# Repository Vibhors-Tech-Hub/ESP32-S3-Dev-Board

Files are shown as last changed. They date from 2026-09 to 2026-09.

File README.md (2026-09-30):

# ESP32-S3 Development Board (4-Layer PCB)

A professional-grade, high-performance **ESP32-S3 Development Board**. This hardware implementation uses a 4-layer PCB stackup to optimize signal integrity, accommodate controlled-impedance differential USB paths, and provide a low-noise ground reference for the RF module's wireless performance.

## Features
* **Core Processor:** Powered by the **ESP32-S3-MINI-1** module featuring high-speed 2.4 GHz Wi-Fi and Bluetooth LE connectivity.
* **Dual USB Type-C Connectivity:** 
  * **USB OTG Port:** Direct native connection to the ESP32-S3 USB pins (IO19/IO20) for USB Host/Device applications.
  * **USB to UART Port:** Dedicated programming and debugging interface utilizing a **CP2102N** master bridge.
* **Automated Boot Circuit:** Dual NPN transistor (L8050QLT1G) circuit for hands-free flashing and reset toggling via DTR/RTS signals.
* **Power & Protection:** 
  * Linear LDO regulation (**LD1117S33TR**) providing up to 800mA on the 3.3V rail.
  * Input overcurrent protection via a resettable PPTC Polyfuse.
  * Comprehensive Transient Voltage Suppression (TVS) arrays on all VBUS, CC, and USB Data lines to prevent ESD damage.
* **Peripherals & Debugging:**
  * One addressable **SK6812MINI RGB LED** on GPIO 48 for multi-color status indication.
  * User-accessible Boot (IO0) and Reset tactile pushbuttons.
  * Dedicated test points for high-level JTAG debugging (TMS, TCK, TDO, TDI).
  * Two 23-pin expansion headers exposing extensive GPIO arrays, power rails, and ground pins.

## Stackup Configuration
This project utilizes a standard **4-layer stackup** designed to minimize electromagnetic interference (EMI) and provide solid reference planes for the high-frequency RF layout.

*Traces assigned to `USB_OTG` and `USB_UART` lines are routed as **90Ω differential pairs**.

## Hardware Component Configuration

### Power System
* **Input Options:** Powered via the Native USB-C port, UART USB-C port, or the external expansion headers (+5V).
* **LDO Regulator:** Stabilized by a `10uF` input capacitor, `4.7uF` output capacitor, and standard `100nF` high-frequency bypass filters.
* **Indicator:** An on-board yellow-green LED (`3216SYGC`) provides immediate visual confirmation of a stable 3.3V power rail.

## Manufacturing & Assembly Notes
* **PCB Thickness:** 1.6 mm
* **Material:** FR-4 (High TG150+ recommended due to the RF component thermal profile)

ESP32 S3 dev board schematic

ESP32 S3

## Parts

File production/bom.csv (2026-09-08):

Reference | Qty | Value | DNP | Exclude from BOM | Exclude from Board | Exclude from Simulation | Exclude from Position Files | Footprint | Datasheet
C1,C2,C3,C4,C8 | 5 | 1uF |  |  |  |  | ${EXCLUDE_FROM_POS_FILES} | Capacitor_SMD:C_0402_1005Metric_Pad0.74x0.62mm_HandSolder
C5,C6,C7 | 3 | 10uF |  |  |  |  | ${EXCLUDE_FROM_POS_FILES} | Capacitor_SMD:C_0402_1005Metric_Pad0.74x0.62mm_HandSolder
C9,C11 | 2 | 100nF |  |  |  |  | ${EXCLUDE_FROM_POS_FILES} | Capacitor_SMD:C_0402_1005Metric_Pad0.74x0.62mm_HandSolder
C10 | 1 | 4.7uF |  |  |  |  | ${EXCLUDE_FROM_POS_FILES} | Capacitor_SMD:C_0402_1005Metric_Pad0.74x0.62mm_HandSolder
D1,D7 | 2 | PMEG4010EJ |  |  |  |  | ${EXCLUDE_FROM_POS_FILES} | Diode_SMD:D_SOD-323F | https://datasheet.lcsc.com/lcsc/2204281430_Guangdong-Hottech-1N5819WS_C191023.pdf
D2,D3,D4,D5,D8,D9,D10,D11 | 8 | TPD1E1B04DPYR |  |  |  |  | ${EXCLUDE_FROM_POS_FILES} | Diode_SMD:D_0402_1005Metric_Pad0.77x0.64mm_HandSolder
D6,D12 | 2 | SD05C-7 |  |  |  |  | ${EXCLUDE_FROM_POS_FILES} | Diode_SMD:D_0402_1005Metric_Pad0.77x0.64mm_HandSolder
D13 | 1 | 3216SYGC |  |  |  |  | ${EXCLUDE_FROM_POS_FILES} | LED_SMD:LED_1206_3216Metric_Pad1.42x1.75mm_HandSolder
D14 | 1 | SK6812MINI |  |  |  |  | ${EXCLUDE_FROM_POS_FILES} | LED_SMD:LED_SK6812MINI_PLCC4_3.5x3.5mm_P1.75mm | https://cdn-shop.adafruit.com/product-files/2686/SK6812MINI_REV.01-1-2.pdf
F1 | 1 | 3-161-417 |  |  |  |  | ${EXCLUDE_FROM_POS_FILES} | Fuse:Fuse_1210_3225Metric_Pad1.42x2.65mm_HandSolder
J1,J2 | 2 | 2169900002 |  |  |  |  | ${EXCLUDE_FROM_POS_FILES} | Connector_USB:USB_C_Receptacle_HCTL_HC-TYPE-C-16P-01A | https://www.usb.org/sites/default/files/documents/usb_type-c.zip
J3,J4 | 2 | Conn_01x23 |  |  |  |  | ${EXCLUDE_FROM_POS_FILES} | Connector_PinSocket_2.54mm:PinSocket_1x23_P2.54mm_Vertical
Q1,Q2 | 2 | L8050QLT1G |  |  |  |  | ${EXCLUDE_FROM_POS_FILES} | Package_TO_SOT_SMD:SOT-223-3_TabPin2
R1,R9,R10 | 3 | 10K |  |  |  |  | ${EXCLUDE_FROM_POS_FILES} | Resistor_SMD:R_0402_1005Metric_Pad0.72x0.64mm_HandSolder
R2 | 1 | 1K |  |  |  |  | ${EXCLUDE_FROM_POS_FILES} | Resistor_SMD:R_0402_1005Metric_Pad0.72x0.64mm_HandSolder
R3 | 1 | 47.5K |  |  |  |  | ${EXCLUDE_FROM_POS_FILES} | Resistor_SMD:R_0402_1005Metric_Pad0.72x0.64mm_HandSolder
R4 | 1 | 22.1K |  |  |  |  | ${EXCLUDE_FROM_POS_FILES} | Resistor_SMD:R_0402_1005Metric_Pad0.72x0.64mm_HandSolder
R5,R6,R7,R8 | 4 | 5.1K |  |  |  |  | ${EXCLUDE_FROM_POS_FILES} | Resistor_SMD:R_0402_1005Metric_Pad0.72x0.64mm_HandSolder
R11 | 1 | 470R |  |  |  |  | ${EXCLUDE_FROM_POS_FILES} | Resistor_SMD:R_0402_1005Metric_Pad0.72x0.64mm_HandSolder
SW1,SW2 | 2 | SW_Push |  |  |  |  | ${EXCLUDE_FROM_POS_FILES} | Button_Switch_SMD:SW_Push_1P1T_NO_Vertical_Wuerth_434133025816
TP1 | 1 | TMS |  |  |  |  | ${EXCLUDE_FROM_POS_FILES} | TestPoint:TestPoint_Pad_D1.0mm
TP2 | 1 | TCK |  |  |  |  | ${EXCLUDE_FROM_POS_FILES} | TestPoint:TestPoint_Pad_D1.0mm
TP3 | 1 | TDO |  |  |  |  | ${EXCLUDE_FROM_POS_FILES} | TestPoint:TestPoint_Pad_D1.0mm
TP4 | 1 | TDI |  |  |  |  | ${EXCLUDE_FROM_POS_FILES} | TestPoint:TestPoint_Pad_D1.0mm
U1 | 1 | ESP32-S3-MINI-1 |  |  |  |  | ${EXCLUDE_FROM_POS_FILES} | RF_Module:ESP32-S2-MINI-1 | https://www.espressif.com/sites/default/files/documentation/esp32-s3-mini-1_mini-1u_datasheet_en.pdf
U2 | 1 | LD1117S33TR |  |  |  |  | ${EXCLUDE_FROM_POS_FILES} | Package_TO_SOT_SMD:SOT-223-3_TabPin2 | http://www.st.com/st-web-ui/static/active/en/resource/technical/document/datasheet/CD00000544.pdf
U3 | 1 | CP2102N-QFN24 |  |  |  |  | ${EXCLUDE_FROM_POS_FILES} | Package_DFN_QFN:QFN-24-1EP_4x4mm_P0.5mm_EP2.6x2.6mm | https://www.silabs.com/documents/public/data-sheets/cp2102n-datasheet.pdf

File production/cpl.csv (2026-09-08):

Id | Designator | Footprint | Quantity | Designation | Supplier and ref
1 | C1, C2, C3, C4, C8 | C_0402_1005Metric_Pad0.74x0.62mm_HandSolder | 5 | 1uF
2 | C5, C6, C7 | C_0402_1005Metric_Pad0.74x0.62mm_HandSolder | 3 | 10uF
3 | C9, C11 | C_0402_1005Metric_Pad0.74x0.62mm_HandSolder | 2 | 100nF
4 | C10 | C_0402_1005Metric_Pad0.74x0.62mm_HandSolder | 1 | 4.7uF
5 | D1, D7 | D_SOD-323F | 2 | PMEG4010EJ
6 | D2, D3, D4, D5, D8, D9, D10, D11 | D_0402_1005Metric_Pad0.77x0.64mm_HandSolder | 8 | TPD1E1B04DPYR
7 | D6, D12 | D_0402_1005Metric_Pad0.77x0.64mm_HandSolder | 2 | SD05C-7
8 | D13 | LED_1206_3216Metric_Pad1.42x1.75mm_HandSolder | 1 | 3216SYGC
9 | D14 | LED_SK6812MINI_PLCC4_3.5x3.5mm_P1.75mm | 1 | SK6812MINI
10 | F1 | Fuse_1210_3225Metric_Pad1.42x2.65mm_HandSolder | 1 | 3-161-417
11 | J1, J2 | USB_C_Receptacle_HCTL_HC-TYPE-C-16P-01A | 2 | 2169900002
12 | J3, J4 | PinSocket_1x23_P2.54mm_Vertical | 2 | Conn_01x23
13 | Q1, Q2 | SOT-223-3_TabPin2 | 2 | L8050QLT1G
14 | R1, R9, R10 | R_0402_1005Metric_Pad0.72x0.64mm_HandSolder | 3 | 10K
15 | R2 | R_0402_1005Metric_Pad0.72x0.64mm_HandSolder | 1 | 1K
16 | R3 | R_0402_1005Metric_Pad0.72x0.64mm_HandSolder | 1 | 47.5K
17 | R4 | R_0402_1005Metric_Pad0.72x0.64mm_HandSolder | 1 | 22.1K
18 | R5, R6, R7, R8 | R_0402_1005Metric_Pad0.72x0.64mm_HandSolder | 4 | 5.1K
19 | R11 | R_0402_1005Metric_Pad0.72x0.64mm_HandSolder | 1 | 470R
20 | SW1, SW2 | SW_Push_1P1T_NO_Vertical_Wuerth_434133025816 | 2 | SW_Push
21 | TP1 | TestPoint_Pad_D1.0mm | 1 | TMS
22 | TP2 | TestPoint_Pad_D1.0mm | 1 | TCK
23 | TP3 | TestPoint_Pad_D1.0mm | 1 | TDO
24 | TP4 | TestPoint_Pad_D1.0mm | 1 | TDI
25 | U1 | ESP32-S2-MINI-1 | 1 | ESP32-S3-MINI-1
26 | U2 | SOT-223-3_TabPin2 | 1 | LD1117S33TR
27 | U3 | QFN-24-1EP_4x4mm_P0.5mm_EP2.6x2.6mm | 1 | CP2102N-QFN24

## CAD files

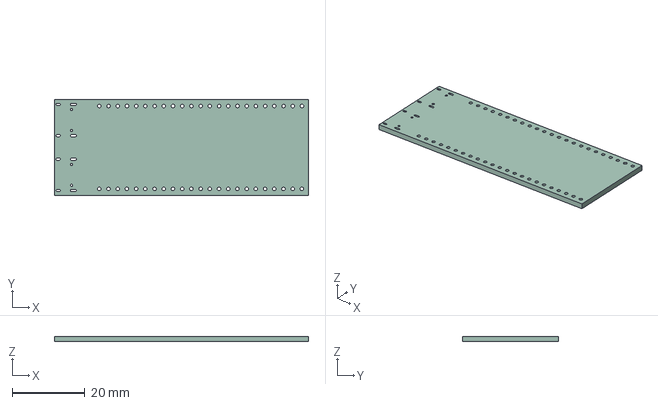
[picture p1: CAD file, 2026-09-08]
3D/ESP32-S3_Dev_Board.step
70.0 x 26.5 x 1.51 mm

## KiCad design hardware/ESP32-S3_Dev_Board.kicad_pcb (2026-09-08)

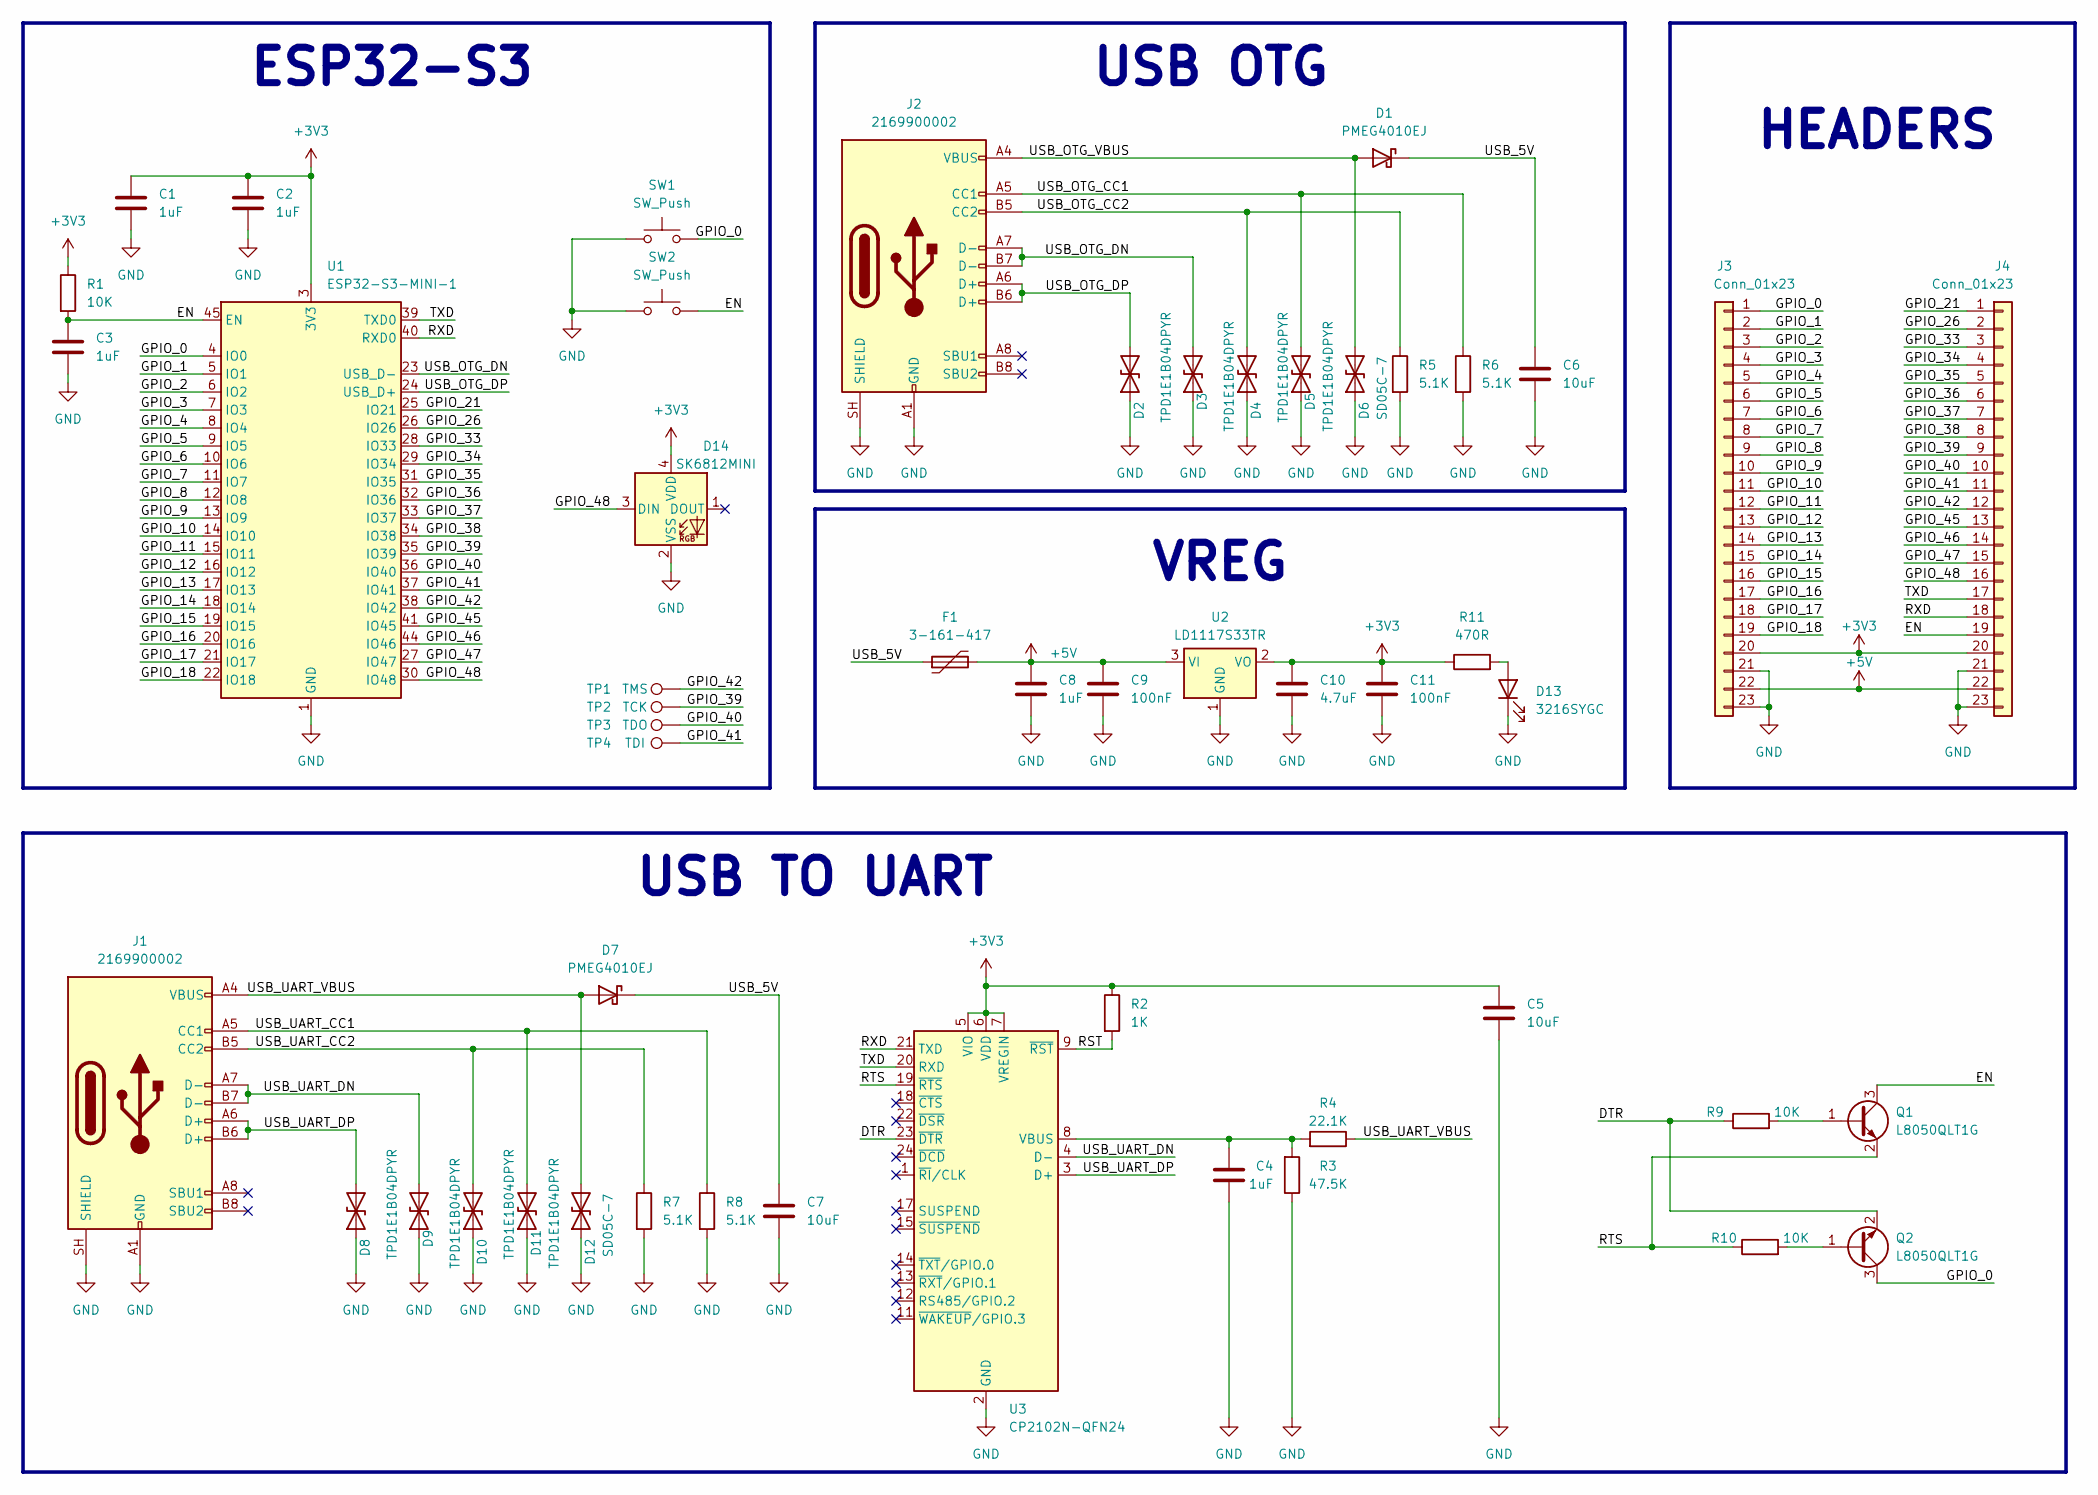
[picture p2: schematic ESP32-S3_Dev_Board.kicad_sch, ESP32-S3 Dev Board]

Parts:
C1, C2, C3, C4, C8: 1uF; C_0402_1005Metric_Pad0.74x0.62mm_HandSolder
C5, C6, C7: 10uF; C_0402_1005Metric_Pad0.74x0.62mm_HandSolder
C9, C11: 100nF; C_0402_1005Metric_Pad0.74x0.62mm_HandSolder
C10: 4.7uF; C_0402_1005Metric_Pad0.74x0.62mm_HandSolder
D1, D7: PMEG4010EJ; D_SOD-323F
D2, D3, D4, D5, D8, D9, D10, D11: TPD1E1B04DPYR; D_0402_1005Metric_Pad0.77x0.64mm_HandSolder
D6, D12: SD05C-7; D_0402_1005Metric_Pad0.77x0.64mm_HandSolder
D13: 3216SYGC; LED_1206_3216Metric_Pad1.42x1.75mm_HandSolder
D14: SK6812MINI; LED_SK6812MINI_PLCC4_3.5x3.5mm_P1.75mm
F1: 3-161-417; Fuse_1210_3225Metric_Pad1.42x2.65mm_HandSolder
J1, J2: 2169900002; USB_C_Receptacle_HCTL_HC-TYPE-C-16P-01A
J3, J4: Conn_01x23; PinSocket_1x23_P2.54mm_Vertical
Q1, Q2: L8050QLT1G; SOT-223-3_TabPin2
R1, R9, R10: 10K; R_0402_1005Metric_Pad0.72x0.64mm_HandSolder
R2: 1K; R_0402_1005Metric_Pad0.72x0.64mm_HandSolder
R3: 47.5K; R_0402_1005Metric_Pad0.72x0.64mm_HandSolder
R4: 22.1K; R_0402_1005Metric_Pad0.72x0.64mm_HandSolder
R5, R6, R7, R8: 5.1K; R_0402_1005Metric_Pad0.72x0.64mm_HandSolder
R11: 470R; R_0402_1005Metric_Pad0.72x0.64mm_HandSolder
SW1, SW2: SW_Push; SW_Push_1P1T_NO_Vertical_Wuerth_434133025816
TP1: TMS; TestPoint_Pad_D1.0mm
TP2: TCK; TestPoint_Pad_D1.0mm
TP3: TDO; TestPoint_Pad_D1.0mm
TP4: TDI; TestPoint_Pad_D1.0mm
U1: ESP32-S3-MINI-1; ESP32-S2-MINI-1
U2: LD1117S33TR; SOT-223-3_TabPin2
U3: CP2102N-QFN24; QFN-24-1EP_4x4mm_P0.5mm_EP2.6x2.6mm

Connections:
+3V3: C1.1, C2.1, C5.1, C10.1, C11.1, D14.4 (VDD), J3.20, J4.20, R1.1, R2.1, R11.1, U1.3 (3V3), U2.2 (VO), U3.5 (VIO), U3.6 (VDD), U3.7 (VREGIN)
+5V: C8.1, C9.1, F1.2, J3.22, J4.22, U2.3 (VI)
/DTR: Q2.2 (Emitter), R9.1, U3.23 (~DTR)
/EN: C3.1, J4.19, Q1.3 (Collector), R1.2, SW2.2, U1.45 (EN)
/GPIO_0: J3.1, Q2.3 (Collector), SW1.2, U1.4 (IO0)
/GPIO_1: J3.2, U1.5 (IO1)
/GPIO_2: J3.3, U1.6 (IO2)
/GPIO_3: J3.4, U1.7 (IO3)
/GPIO_4: J3.5, U1.8 (IO4)
/GPIO_5: J3.6, U1.9 (IO5)
/GPIO_6: J3.7, U1.10 (IO6)
/GPIO_7: J3.8, U1.11 (IO7)
/GPIO_8: J3.9, U1.12 (IO8)
/GPIO_9: J3.10, U1.13 (IO9)
/GPIO_10: J3.11, U1.14 (IO10)
/GPIO_11: J3.12, U1.15 (IO11)
/GPIO_12: J3.13, U1.16 (IO12)
/GPIO_13: J3.14, U1.17 (IO13)
/GPIO_14: J3.15, U1.18 (IO14)
/GPIO_15: J3.16, U1.19 (IO15)
/GPIO_16: J3.17, U1.20 (IO16)
/GPIO_17: J3.18, U1.21 (IO17)
/GPIO_18: J3.19, U1.22 (IO18)
/GPIO_21: J4.1, U1.25 (IO21)
/GPIO_26: J4.2, U1.26 (IO26)
/GPIO_33: J4.3, U1.28 (IO33)
/GPIO_34: J4.4, U1.29 (IO34)
/GPIO_35: J4.5, U1.31 (IO35)
/GPIO_36: J4.6, U1.32 (IO36)
/GPIO_37: J4.7, U1.33 (IO37)
/GPIO_38: J4.8, U1.34 (IO38)
/GPIO_39: J4.9, TP2.1 (1_1), U1.35 (IO39)
/GPIO_40: J4.10, TP3.1 (1_1), U1.36 (IO40)
/GPIO_41: J4.11, TP4.1 (1_1), U1.37 (IO41)
/GPIO_42: J4.12, TP1.1 (1_1), U1.38 (IO42)
/GPIO_45: J4.13, U1.41 (IO45)
/GPIO_46: J4.14, U1.44 (IO46)
/GPIO_47: J4.15, U1.27 (IO47)
/GPIO_48: D14.3 (DIN), J4.16, U1.30 (IO48)
/RST: R2.2, U3.9 (~RST)
/RTS: Q1.2 (Emitter), R10.1, U3.19 (~RTS)
/RXD: J4.18, U1.40 (RXD0), U3.21 (TXD)
/TXD: J4.17, U1.39 (TXD0), U3.20 (RXD)
/USB_5V: C6.1, C7.1, D1.1 (K), D7.1 (K), F1.1
/USB_OTG_CC1: D5.2 (A2), J2.A5 (CC1), R6.1
/USB_OTG_CC2: D4.2 (A2), J2.B5 (CC2), R5.1
/USB_OTG_DN: D3.2 (A2), J2.A7 (D-), J2.B7 (D-), U1.23 (USB_D-)
/USB_OTG_DP: D2.2 (A2), J2.A6 (D+), J2.B6 (D+), U1.24 (USB_D+)
/USB_OTG_VBUS: D1.2 (A), D6.2 (A2), J2.A4 (VBUS), J2.A9 (VBUS), J2.B4 (VBUS), J2.B9 (VBUS)
/USB_UART_CC1: D11.2 (A2), J1.A5 (CC1), R8.1
/USB_UART_CC2: D10.2 (A2), J1.B5 (CC2), R7.1
/USB_UART_DN: D9.2 (A2), J1.A7 (D-), J1.B7 (D-), U3.4 (D-)
/USB_UART_DP: D8.2 (A2), J1.A6 (D+), J1.B6 (D+), U3.3 (D+)
/USB_UART_VBUS: D7.2 (A), D12.2 (A2), J1.A4 (VBUS), J1.A9 (VBUS), J1.B4 (VBUS), J1.B9 (VBUS), R4.1
GND: C1.2, C2.2, C3.2, C4.2, C5.2, C6.2, C7.2, C8.2, C9.2, C10.2, C11.2, D2.1 (A1), D3.1 (A1), D4.1 (A1), D5.1 (A1), D6.1 (A1), D8.1 (A1), D9.1 (A1), D10.1 (A1), D11.1 (A1), D12.1 (A1), D13.1 (K), D14.2 (VSS), J1.A1 (GND), J1.A12 (GND), J1.B1 (GND), J1.B12 (GND), J1.SH (SHIELD), J2.A1 (GND), J2.A12 (GND), J2.B1 (GND), J2.B12 (GND), J2.SH (SHIELD), J3.21, J3.23, J4.21, J4.23, R3.1, R5.2, R6.2, R7.2, R8.2, SW1.1, SW2.1, U1.1 (GND), U1.2 (GND), U1.42 (GND), U1.43 (GND), U1.46 (GND), U1.47 (GND), U1.48 (GND), U1.49 (GND), U1.50 (GND), U1.51 (GND), U1.52 (GND), U1.53 (GND), U1.54 (GND), U1.55 (GND), U1.56 (GND), U1.57 (GND), U1.58 (GND), U1.59 (GND), U1.60 (GND), U1.61 (GND), U1.62 (GND), U1.63 (GND), U1.64 (GND), U1.65 (GND), U2.1 (GND), U3.2 (GND), U3.25 (GND)
unnamed: D13.2 (A), R11.2
unnamed: Q1.1 (Base), R9.2
unnamed: Q2.1 (Base), R10.2
unnamed: C4.1, R3.2, R4.2, U3.8 (VBUS)

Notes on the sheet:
ESP32-S3
USB OTG
USB TO UART
VREG
HEADERS

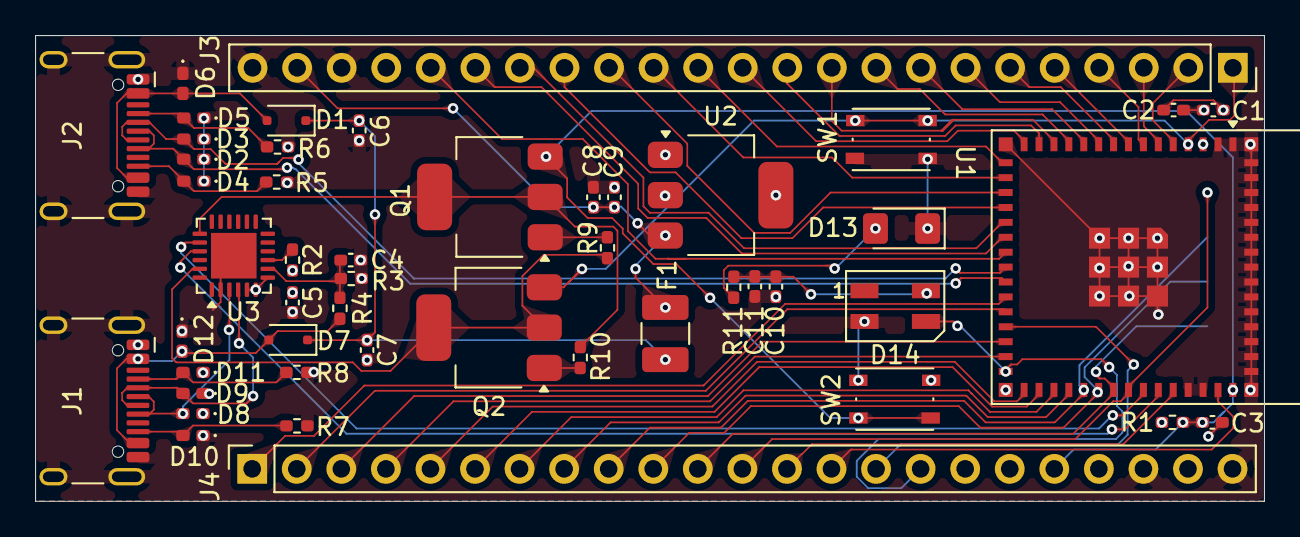
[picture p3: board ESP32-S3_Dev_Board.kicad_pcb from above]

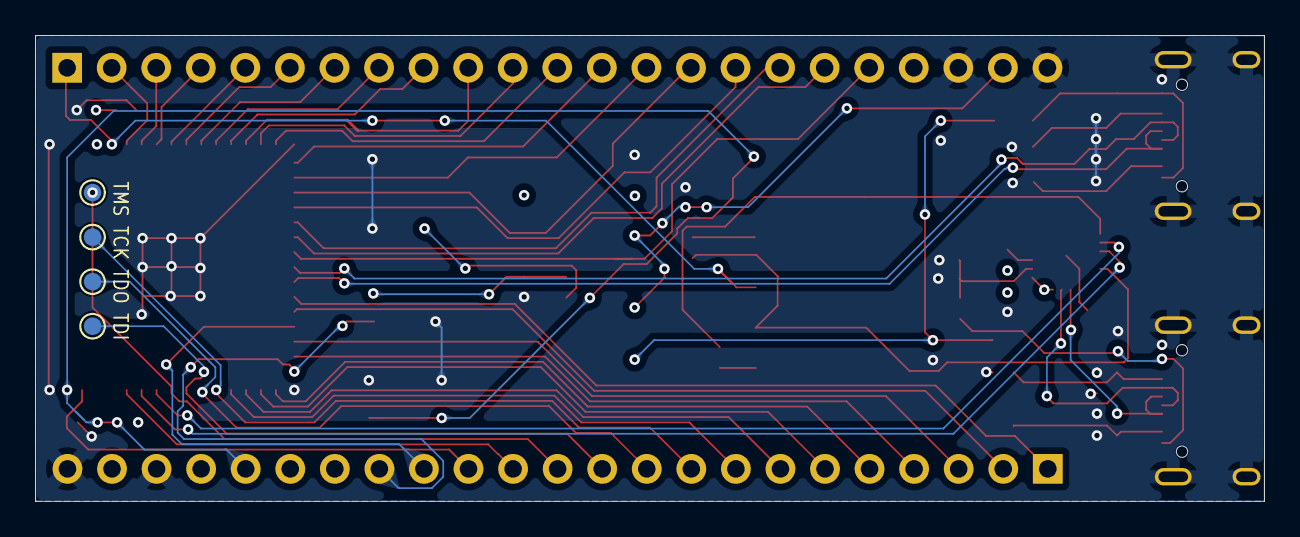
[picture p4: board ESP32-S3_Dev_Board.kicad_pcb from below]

Board: 4 copper layers, 70.0 x 26.5 mm, 52 parts (4 on the bottom side), 59 nets.

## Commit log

2026-09-30 Include ESP32-S3 image in README
2026-09-30 Add ESP32-S3 Schematic image
2026-10-27 Refine README for ESP32-S3 Development Board
